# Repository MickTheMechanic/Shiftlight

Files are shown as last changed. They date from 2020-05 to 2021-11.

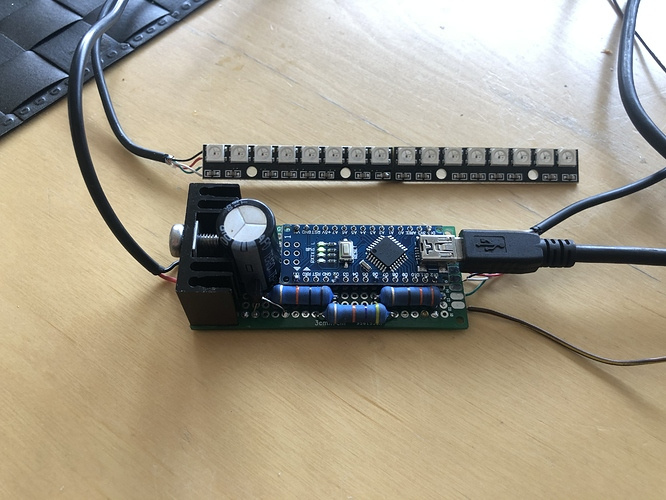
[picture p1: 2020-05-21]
Finished board.jpeg

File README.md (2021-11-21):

## Open-source Shiftlight

[vid](https://youtu.be/9aou7hNQFXM)

# An opensource shiftlight project using Arduino and Neopixel products

In this repository you will find;
- The .ino file that you can upload directly to your Arduino 
- A .png image of the wiring diagram
- A .jpeg image of how the finished assembly should look
- An .stl file for a housing for the shift light (Suits Daihatsu, but can be modified)
- An .stl file for a housing for the Arduino
- An .md file containing a detailed parts list.

# Currently the easiest DIY shiftlight on the world wide web, you're welcome ;)

b73128e0c34c0271b41c925a6889e2ce635afe49

02e61ff9bd5349ea1deae73b9c1757d51cc9f0a8

## Please note, there is a mistake in this schematic. A corrected schematic is shown in issue #4

72bc0fe16fb227eac94da071f4eaca564dbe03f3

77c8a71d32cf7a6d5637833e3bfcc7f0d2fdef7a

Notes:

- This example uses a voltage divider and transistor to pull down the the tacho signal from 12v,

if your car uses a 5v tacho signal this is not needed.

- You will need to download and install the adafruit neopixel library for IDE

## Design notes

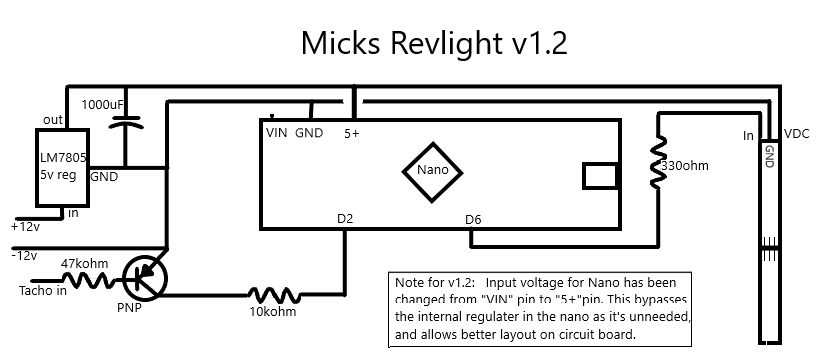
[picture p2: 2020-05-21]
revlight.png

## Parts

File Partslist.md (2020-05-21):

- Arduino nano
- 70mm x 30mm double sided Prototype PCB
- 1x 330 ohm resistor
- 1x 47 kohm resistor
- 1x 10 kohm resistor
- 1x 5v reg #7805
- 1x heatsink #V4330N (fits perfectly to the board and voltage reg)
- 1x PNP transistor #2N3906
- 1x 1000uF (min 6v) capacitor
- 2x neopixel 8LED strips #WS2812

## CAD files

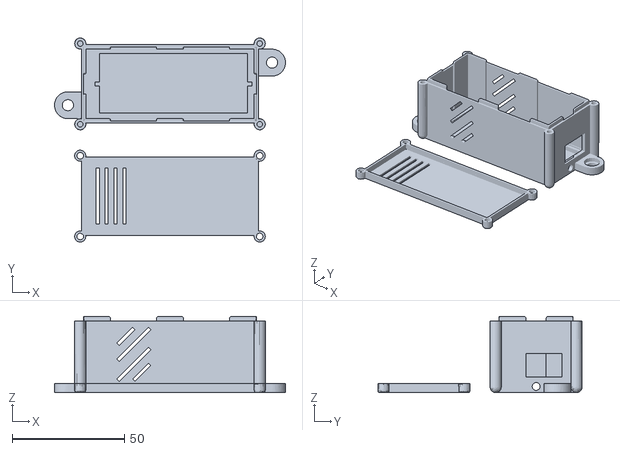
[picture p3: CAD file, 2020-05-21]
Shiftlight ECU case.stl
103.0 x 91.0 x 34.0

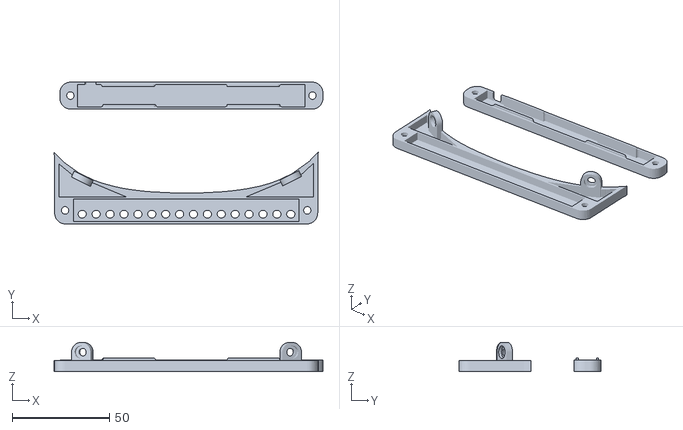
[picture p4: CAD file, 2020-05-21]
Shiftlight case Sirion M100.stl
138.5 x 73.0 x 15.0

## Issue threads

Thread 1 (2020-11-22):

Program only runs on USB power?

drftrds87, 2020-11-22:
I'm trying to use an external power source to power the Arduino nano but the program will not run with an external 12v to VIN. Any help would be appreciated.

michaelwilkinson1992, 2020-11-23:
You cannot run the Arduino Nano on 12v, it is a 5V Board. You need to build the circuit shown in the schematic, there is a voltage regulator included (LM7805).

You may need to purchase a new board, I would imagine the 12v directly to VIN has done some permanent damage.

michaelwilkinson1992, 2020-11-23:
Also note: the LM7805 has NO polarity protection, if you accidentally switch the wires during installation, the regulator will be permanently damaged

Closed 2020-11-23.

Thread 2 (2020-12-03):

Tach Input

adamgav5000, 2020-12-03:
Hi Michael,

I'm really looking forward to building and running this project. I have a few questions about the incoming tach signal...

Do you know where your vehicle reads its tach signal from? Is it the negative side of the coil?
You say the resistors etc are based off of a 12v signal. Is this signal a clean 12v square wave?

I am trying to get this to work with a YX160 pitbike engine which does not have an original tachometer signal. I am planning on taking a reading from the negative of the primary side of the coil. I believe this is susceptible to voltage surges of negative  200V. I am yet to check out the signal with an oscilloscope, but have found other peoples readings that suggest it may be a sawtooth pulse rather than a nice square pulse.

Can you suggest a method to reduce and clean the voltage to a level that can be applied to the base of the transistor.
What is the target voltage and current that is needed to be sent to the base?

My coding ability is non existent as is my circuit design knowledge, so any help is much appreciated!

Kind Regards
Adam

michaelwilkinson1992, 2020-12-03:
Hi, this particular circuit is designed to use with a 12v sqare wave signal.

The signal is the tacho output from the ECU.

You could definatly use the coil negative as a signal, but you would need to update the code a little bit to match the frequency of the coil signal. This can be easily calculated, all you need to know is how often the coil fires for one engine rotation.

But... I guess your bike does not have electronic ignition, rather a magneto style ignition coil. In this case you will need to do some research on how to convert this to some kind of signal that is not greater than 5v ( It shouldnt matter if you have a sawtooth, square wave, or sinus wave signal, as the arduino will still register the top and bottom of the signal as high/low).

The important thing is the lows are 0v and the highs are somewhere in the ballpark of 3-5v.

I reccomend reading the signal first with an occilliscope, if your signal does not exceed 15v the existing circuit should work.
If you are getting high induction spikes then you will need to clean up the signal somehow.

adamgav5000, 2020-12-13:
Sorry for the slow reply. Thank you for the information!

Closed 2021-11-21.

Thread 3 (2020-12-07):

Trying to run on a 6 cylinder

cpatersontn, 2020-12-07:
Mick,
Thanks for posting this project. We're looking forward to getting this running on our race car. We have a 1991 BMW 325i running the 6 cylinder engine. We've built the board as you specified and uploaded a modified version of your code. We are pulling the tach signal from the ECU wire that feeds the factory in-dash tach. The factory tach is working fine so we know it's getting good signal. The engine is firing 3X per revolution so we are assuming the frequency (at a given rpm) is (RPM/60)*3. We are testing at lower RPMs (don't want to upset the neighbors with rev'ing it to redline :)) so we calculated the lower RPMs between 1500 and 3100 (75Hz-155Hz). It idles at 800 RPM.

Once we start the car, the start-up sequence works and they flash one by one and then go off. However, regardless of how high we rev it, nothing else lights up. It's like it does the start-up sequence then somewhere it gets hung-up on lighting the LEDs (0,0,0). Stumped.

Here's the modified code:

//Shift Light V1.5

#include <Adafruit_NeoPixel.h>

#define PIN            6  //LED Data Pin
#define NUMPIXELS      16  //number of leds connected
Adafruit_NeoPixel pixels = Adafruit_NeoPixel(NUMPIXELS, PIN, NEO_GRB + NEO_KHZ800);

//Calculate the frequency of the tacho signal you are using and adjust the following values accordingly
//example: for a standard tacho signal on a 4 cylinder engine the frequeny is equal to the RPM divided by 30
const unsigned int onFrequency = 20;  //startup sequence, value represents engine speed higher than cranking and lower than idle
const unsigned int minFrequency = 75; // minimum frequency to begin turning on LEDs
const unsigned int maxFrequency = 155; // maximum frequency in normal range, after this value shift flash will occur
const unsigned int shiftFrequency = 165; // frequency range from max to shift when shifting should happen, after this value overrev flash will occur

//Set the color for each LED in the neo pixel strip
//Colors are set using an RGB value ranging from (0,0,0) to (255,255,255)
const uint32_t tachColor[NUMPIXELS] = {
  Adafruit_NeoPixel::Color(0, 120, 0),//green
  Adafruit_NeoPixel::Color(0, 120, 0),
  Adafruit_NeoPixel::Color(0, 120, 0),
  Adafruit_NeoPixel::Color(15, 105, 0),
  Adafruit_NeoPixel::Color(30, 90, 0),
  Adafruit_NeoPixel::Color(45, 75, 0),
  Adafruit_NeoPixel::Color(60, 60, 0),//orange
  Adafruit_NeoPixel::Color(75, 45, 0),
  Adafruit_NeoPixel::Color(90, 30, 0),
  Adafruit_NeoPixel::Color(105, 15, 0),
  Adafruit_NeoPixel::Color(120, 0, 0),//red
  Adafruit_NeoPixel::Color(0, 0, 120),//blue
  Adafruit_NeoPixel::Color(0, 0, 120),
  Adafruit_NeoPixel::Color(0, 0, 120),
  Adafruit_NeoPixel::Color(0, 0, 120),
  Adafruit_NeoPixel::Color(0, 0, 120),
};

//Set the frequency when each LED should turn on
//First LED turns on at minFrequency
const unsigned int lightShiftFreq[NUMPIXELS] = {
  minFrequency,
  80,
  85,
  90,
  95,
  100,
  105,
  110,
  115,
  120,
  125,
  130,
  135,
  140,
  145,
  150,
};

bool hasStartupSequenceRun = false; // only run startup sequence one time
const byte tachPin = 2;
unsigned long igfreq;

void setup() {
  pixels.begin(); // This initializes the NeoPixel library.
}

void loop() {

  float ighigh, iglow;
  unsigned long igcal1, igcal2;

  //measure period of tach signal
  ighigh = pulseIn(tachPin, HIGH);
  iglow = pulseIn(tachPin, LOW);

  igcal1 = 1000 / ((ighigh / 1000) + (iglow / 1000));

  //do it again
  ighigh = pulseIn(tachPin, HIGH);
  iglow = pulseIn(tachPin, LOW);

  igcal2 = 1000 / ((ighigh / 1000) + (iglow / 1000));

  //to filter out some noise, we only consider our measurement valid if they are similar in value, we accept the average.
  if ((igcal1 - igcal2) < 8) {
    igfreq = (igcal1 + igcal2) / 2;
  }

  if (hasStartupSequenceRun == false) {
    if (igfreq > onFrequency) {
    //run start sequence
    //LEDs will light up, flash and light out upon starting the engine.
      for ( int i = 0; i < NUMPIXELS; ++i) {
        pixels.setPixelColor(i, tachColor[i]);
        pixels.show();
        delay(50);
      }
      for(int a=0; a<10; a++) {
        pixels.fill(pixels.Color(0, 0, 120));
    	pixels.show();
    	delay(20);
    	pixels.fill(pixels.Color(0, 0, 0));
    	pixels.show();
    	delay(20);
       }
       for ( int i = 0; i < NUMPIXELS; ++i) {
        pixels.setPixelColor(i, tachColor[i]);
        pixels.show();
        }
       for ( int i = NUMPIXELS-1; i >= 0; --i) {
        pixels.setPixelColor(i, pixels.Color(0, 0, 0));
        pixels.show();
        delay(50);
      }
      hasStartupSequenceRun = true;
      pixels.fill(pixels.Color(0, 0, 0));
      pixels.show();
    }
      if (igfreq < onFrequency) {
    //resets hasStartupSequenceRun to false if engine stops but Arduino remains powered,
    //startupsequence will rerun upon restarting the engine
	hasStartupSequenceRun = false;
    }
  }

  if (igfreq < maxFrequency) {

    // normal operating range
    for ( int i = 0; i < NUMPIXELS; ++i) {
      if (igfreq > lightShiftFreq[i]) {
        pixels.setPixelColor(i, tachColor[i]);
      }
      else {
        pixels.setPixelColor(i, pixels.Color(0, 0, 0));
      }
    }
    pixels.show();
  }
  else if (igfreq >= maxFrequency && igfreq < shiftFrequency) {
    //shift flash
    //default color=blue
    //to change shift flash color, edit RGB value in following line
    pixels.fill(pixels.Color(0, 0, 120));
    pixels.show();
    delay(20);
    pixels.fill(pixels.Color(0, 0, 0));
    pixels.show();
    delay(20);
  }

  else if (igfreq >= shiftFrequency) {
    //overrev flash
    //default color=red
    //to change overrev flash color, edit RGB value in following line
    pixels.fill(pixels.Color(120, 0, 0));
    pixels.show();
    delay(20);
    pixels.fill(pixels.Color(0, 0, 0));
    pixels.show();
    delay(20);
  }
}

MickTheMechanic, 2020-12-07:
If you have an ocsilloscope please check your Signal wire and confirm you have a 12v square wave (I am not familiar with BMW Tacho Signal, it’s possible it’s a 5v Signal).

Does your car have a single coil with a distributor? If so, please try using coil negative.

Report back with results.

cpatersontn, 2020-12-07:
We don't have an ocsilloscope. If it's a 5V signal, then what do we need to modify (hardware and software)?

Yes, single coil with distributor. We tried the coil negative and it was very noisy.... LEDs jumped all over the place.

MickTheMechanic, 2020-12-07:
If its a 5v signal then you can feed it directly into the arduino, bypassing the transistor. But if its not 5v and you do that, you'll fry your arduino.

Do you maybe have a video showing what it looks like when using coil negative?

MickTheMechanic, 2020-12-07:
You could even check with a multimeter, if its a 12v signal you should read about 6v on the signal wire with engine running. If its a 5v signal you should read about 2-3v

cpatersontn, 2020-12-08:
Tach signal from ECU is 7.9V (set to DC on multimeter).

Here's the shift light attached to the negative on the coil. It always goes through the start-up sequence then just flashes red as at idle if it's over-reving. Our shiftFrequency is set to 165Hz just for testing but that should equate to 3300rpm if our equation is correct for this 6-cylinder (RPM/60)*3)

Link to video: [https://www.facebook.com/chris.paterson.399/videos/10219498587075256/](url)

MickTheMechanic, 2020-12-08:
Link doesnt work.

Are you able to test on another car?
Perhaps there is a problem with the circuit.

Have you tried using the original code, unchanged?

MickTheMechanic, 2020-12-08:
Can you upload photos of your circuit?
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
MickTheMechanic, 2020-12-19:
Its reading about 40kHz, but the signal should only be 100-200 Hz. There is some kind of interferance there somewhere.

-Double check your circuit, there is possibly something amiss there thats allowing interferance to be read as pulses.

-Check the routing of the signal wire, it should not be run along side any kind of signal wires for valves that are powered by PWM (things like idle control valve, AGR and so on)

-If you have the posibilitiy, perform a test without the alternator connected, its possible the alternator voltage is producing a ripple that is being picked up by the arduino.

It seems very strange that the arduino is reading such a high frequency, and not reading anything on the tacho signal. Perhaps the arduino has been damaged in some way, possibly by a voltage surge from the coil (induction voltage when the points/coil driver opens)

I have attached some extra photos so you can check your circuit.
It is also important that you are using the same kind of transistor (PNP, not NPN)

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

MickTheMechanic, 2020-12-19:
Please provide accurate information about your car, make model, build date, engine, ECU. I will take a look at work on monday and see if I can find a wiring diagram/somewhere where you can pick up a signal

cpatersontn, 2020-12-19:
Thanks Mick. Will check those this weekend.

Car is a 1991 BMW 325i, 6 cylinder. Stock ECU.

Here's my part list:
330k ohm 5W resistor
10k ohm 5W resistor
47k ohm 3W resistor
PNP Transistor ON Semi Bipolar Transistors
Heat sink
5 volt regulator
1000uF 20% 16V Vishay Aluminum Electrolytic Capacitor
Arduino Nano
Adafruit LEDs

MickTheMechanic, 2020-12-21:
If you have the 20 pin style BMW diagnostic port, try Pin 1 (listed as Drehzahl in below picture)

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

MickTheMechanic, 2020-12-21:
Does your car have one ignition coil, or 6.
please provide a picture of how you have connected to the ignition coil.

cpatersontn, 2020-12-22:
Our car has one standard cylindrical coil. Here is the attachment point to the negative side. I ran it directly to the Arduino without any other wires around it.
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

MickTheMechanic, 2021-02-24:
Did you get it working?

cpatersontn, 2021-03-01:
Unfortunately, no. The issue was either I got zero signal from the factory tach wire from the ECU or the signal from the coil was too noisy and just bounced around the signal. Thanks for your help and understanding the code and circuit. May just need to build another one from scratch to see if it was a hardware issue.

Sent from my iPhone

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

MickTheMechanic, 2021-04-06:
Hi,

I was working on a project recently which reminded me of your problem.

The project used some transistors, and I came to learn the hard way that not all transistors have the same pinout. E,C, and B pins vary from manufacturer to manufacturer. I even had two 2N2222A transistors with different pin layout, the only difference was a prefix printed on the housing.

I thought maybe this could be the problem. If you are still interested in getting this project up and running it might be a good place to start with the troubleshooting. You would need to download the datasheet for the particular transistor you have (should be available from the seller website) and confirm the pin layout matches how you have it connected.

cpatersontn, 2021-04-06:
Interesting..... will need to check

Would a higher resistor value cause issues with this circuit?

Sent from my iPhone

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

MickTheMechanic, 2021-04-06:
Yes it could have an influence. Transistors are not actually switched by the amount of voltage, but rather by the amount of current that runs through the base. This current is limited by the resistor connected to the base, so a different value resistor could have a negative effect.

also Different transistors have Different characteristics regarding switching speed, switching current, and so on.

I would first of all check the datasheet and make sure you have the pins connected correctly (in my last project I was pulling my hair out trying to find the problem, turns out the transistor I used that had „similar properties“ also had a different pin layout!).
If that doesn’t work I would swap it out with one that has the same part number as listed in the parts list, as the resistors have been sized
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

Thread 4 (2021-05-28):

Trying to get the project running

Lakshitha747, 2021-05-28:
Mike,

Thanks for the project. Trying to get the code working for my honda (4 cylinder). Did everything according to your diagram without using the LM7805 as im powering my Arduino Uno from my laptop for now. This works but I'm getting frequency values when my ECU wire is not connected and the the idle frequency is showing in the high 40000. The -12v, is it fixed to the chasis as earth or?. If you could find the time to help me that would be really great. Im sort of new to this and I have no idea whats going on

Thank you

MickTheMechanic, 2021-05-28:
Very strange indeed... the same problem was reported in #3

I will need to look into this further. I know of several other people who have successfully built the project without issues, so I am fairly confident it’s not an issue with the code.

Can you provide more information, like what you are using as a signal, does the bug also appear when you have the signal wire connected etc etc...

Lakshitha747, 2021-05-28:
Thanks for your help,

Yeah its the same when its connected. It cant be an issue with the code cause the first time I tested it I got the proper values. The idle frequency was at 30Hz and when pin was removed it was showing 0Hz

Lakshitha747, 2021-05-28:
Working on getting you the pictures. Actually didn't expect a reply so quickly

MickTheMechanic, 2021-05-28:
I found the problem, my wiring diagram is wrong... I will post an updated version in a few moments

Lakshitha747, 2021-05-28:
Thank you for the help.

MickTheMechanic, 2021-05-28:
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

please try this configuration with the PNP transistor and let me know how it works.

Also make sure your Arduino gnd pin has a connection to the car body when you are powering via the laptop.

Lakshitha747, 2021-05-28:
Alright thanks. I'll let you know how this goes

MickTheMechanic, 2021-05-30:
Did it work out for you?

Lakshitha747, 2021-05-30:
Sorry waiting on the transistors. Country is on lock down bit hard to get the stuff. I'll update the forum as soon as I get the parts and build the circuit. Is there another alternative to the transistor that you know of other than the PNP transistor #2N3906?

MickTheMechanic, 2021-05-30:
Do you have any other PNP transistors?

Lakshitha747, 2021-05-30:
s8550, s8050 transistor

MickTheMechanic, 2021-05-30:
You can try the S8550, it would probably work.

Lakshitha747, 2021-05-30:
Alright. I'll try with the S8550 and let you know

MickTheMechanic, 2021-06-03:
Any luck?

Lakshitha747, 2021-06-03:
Trying it right now with a S8050 transistor (cant seem to find my S8550 transistors). Trying to print igfreq but the serial monitor shows nothing. I have a random println in the loop and even that doesn't print. Can this be expected when running with this transistor?

Lakshitha747, 2021-06-03:
Ok so now its printing a bunch of zeros

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

Lakshitha747, 2021-06-03:
Yeah now I took the ground off and now its showing 50s 49s. When the revs increase it increases by like +1 not much and on idle and even when the vehicle is off its saying a constant 50. Looks like the transistor. I'll have get new ones

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

Lakshitha747, 2021-06-05:
Well my transistors finally came and I tried it with the 2N3906 and it works. Thanks for all your help with this. Just one more thing, when I do use this with the 12v, I can use a step down converter to reduce the voltage and power the Arduino and the rest of the circuitry will stay the same?

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

The frequencies are set pretty low

MickTheMechanic, 2021-06-05:
Yes, you can use either a stepdown or a linear regular, and the rest will stay the same.

Which wiring diagram worked for you in the end?

Lakshitha747, 2021-06-05:
This one

 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

Lakshitha747, 2021-06-05:
I'll close this issue now. Again thanks for your help with this.

JeFeRoJo, 2021-11-11:
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

Hello.

I just created an account here to ask you how you have implemented the display with the RPM counter.
I am also trying to get the project to work on my Honda (EUDM Civic EK3) and am going to test it again with the new published diagram.

Thanks!

Closed 2021-06-05.

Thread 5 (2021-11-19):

Trying to make it run (for a long time)

JeFeRoJo, 2021-11-19:
Hello!

First of all, thank you for sharing your project. I was looking to mount something similar in a simple way and this is great.
But not everything is happiness. I've been stuck with your project for almost a year. I can't get it to work.

A few days ago I took up the project again and saw that it updated the circuit (the position of the PNP transistor).

I have reassembled it following the new scheme. Same components.
The code has not been modified and I think that, could the problem be there?

My car is a Honda Civic EK 1996. D15Z6 engine from the European market.
I extract the signal from the cable that connects the original tacho/speedometer (blue wire in my case).
I'm just getting uncontrolled blinks. I attach a small video to show it:

https://www.youtube.com/watch?v=rK0u13ykE58

Could it be wrong values   in the code for the engine?
Any help would be appreciated. I would like to make it work after so long.

Thanks and regards

MickTheMechanic, 2021-11-20:
Hi,

My guess is your car uses some other kind of signal for the Tacho. Do you have access to an oscilloscope to check what kind of signal you have?

JeFeRoJo, 2021-11-20:
I don't have an oscilloscope because I've never used one but I can try to get a "cheap" one like this: shorturl.at/szQ16
It's enough?

However, in another thread here, a user has made it work on his Honda. It also added a screen.

For this reason, I was wondering if I have to edit values   of the code u is a circuit problem.

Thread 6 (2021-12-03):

finding schematics

eddygor, 2021-12-03:
Hi Mick. First off fantastic job, Thank you for posting this project. Your instructions are very clear even for a learner like myself. I am hoping to adapt this to work on my 1986 golf GTI. only issue I'm having is the note on the bottom of the schematic says  there is a mistake, and the correct schematic is in "issue 4". Where can I find issue 4 (or the correct schematic) as I am new to GitHub. many thanks eddy

hope I've posted this in the correct place

MickTheMechanic, 2021-12-04:
#4

Closed 2023-01-10.

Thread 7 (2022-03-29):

For building up the Shiftlight

sono0312, 2022-03-29:
Hello,
I am trying to build up your shiftlight for my car BMW E90 2005 which has an OBD2 port. I believe that it can give a signal RPM from PIN-9 on the OBD2 connector (according to my research).

I am still a beginner to do the sketch on the Arduino and need more time to learn/modify your sketch you posted already to match with what I want. I have checked your schematics and info of corrections on the wiring of PNP. I hope that 12-14V together with RPM can be wired from OBD2 as well.

I wonder if a register of 10k ohms on the Collector is a proper value for driving the Arduino D2 input? Is it working properly?

Thankyou for your help.

br//sono

sono0312, 2022-04-03:
I am trying to check the parameter around PNP transistor in the circuit below. I wonder if a register 10k ohms between Collector and G are a proper value. It might be too large. If Ic should be 20mA or so the register could be 250 ohms instead of 10k ohms.

https://github.com/MickTheMechanic/Shiftlight/issues/4#issuecomment-850627599

sono0312, 2022-04-03:
> I am trying to check the parameter around PNP transistor in the circuit below. I wonder if a register 10k ohms between Collector and G is a proper value. It might be too large. If Ic should be 20mA or so the register could be 250 ohms instead of 10k ohms.
>
> [#4 (comment)](https://github.com/MickTheMechanic/Shiftlight/issues/4#issuecomment-850627599)

I realized that 10k ohms on Corrector could be a pull-down register so it should not be a problem. Am I right?

MickTheMechanic, 2022-04-05:
It is a voltage divider to make an appropriate signal voltage

sono0312, 2022-04-05:
> It is a voltage divider to make an appropriate signal voltage

Hello,
Thankyou for the reply.
Now I was able to make a shift-light according to your information. Everything is working fine so far. To check the all the signal function I changed the frequency range to lower so that the test can be done at the lower RPM.
To check the Tach signal from OBD2, a serial monitor enabled so that I can seen the real time frequency value in response to the axel work.

Again, thankyou for your job done to make it happen!

regards

sono0312, 2022-04-16:
Found that a Line 121 starting with  "if (igfreq < onFrequency) {" and onwards need to be corrected.

===
      hasStartupSequenceRun = true;
      pixels.fill(pixels.Color(0, 0, 0));
      pixels.show();
    }
      if (igfreq < onFrequency) {
    //resets hasStartupSequenceRun to false if engine stops but Arduino remains powered,
    //startupsequence will rerun upon restarting the engine
	hasStartupSequenceRun = false;
    }
  }
===

it should be out side of startup sequence like below.

===
    }
  }
  if (igfreq < onFrequency) {
  //resets hasStartupSequenceRun to false if engine stops but Arduino remains powered,
  //startupsequence will rerun upon restarting the engine
    hasStartupSequenceRun = false;
===

otherwise "hasStartupSequenceRun" will never become false even the engine stops but Arduino remains powered.

sono0312, 2022-04-16:
Found that a Line 121 starting with "if (igfreq < onFrequency) {" and onwards need to be corrected.

  **hasStartupSequenceRun = true;
  pixels.fill(pixels.Color(0, 0, 0));
  pixels.show();
}
  if (igfreq < onFrequency) {
//resets hasStartupSequenceRun to false if engine stops but Arduino remains powered,
//startupsequence will rerun upon restarting the engine
hasStartupSequenceRun = false;
}
}**

it should be out side of startup sequence like below.

**}
}
if (igfreq < onFrequency) {
//resets hasStartupSequenceRun to false if engine stops but Arduino remains powered,
//startupsequence will rerun upon restarting the engine
hasStartupSequenceRun = false;**

otherwise "hasStartupSequenceRun" will never become false even the engine stops but Arduino remains powered.

MickTheMechanic, 2022-04-16:
thanks, ill update it when I have a chance to test it out

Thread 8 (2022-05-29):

tachometer wire

GH-WRX, 2022-05-29:
How are you sure it’s pin 9 on the obd2 connector?? every pin out i try and look at all says thier manufacturers, but i can’t find any information on what they are??

MickTheMechanic, 2022-05-29:
Pin 9 on the obd is reserved for manufacturer specific use, which on Daihatsu happens to be the RPM signal.

Baileyyyyy, 2022-05-29:
Are you able to help me find where the tacho is on a ford focus 2014 mk3? I cant find any information and the ford forums arnt any help; I know toyota also used 9 as rpm too

MickTheMechanic, 2022-05-30:
You need to do some research, what kind of ignition system you have and where you can tap into an rpm signal

baileyfpv, 2022-06-02:
Hey, found some diagrams, what do you think about the violet wire?
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

baileyfpv, 2022-06-02:
http://excesstext.com/tag/duratec/

there us this website too which has a full diagram of everything in the duratech engine but I cant seem to find the tacho? but that violet wire in the diagram above seems like it could work no? using the coils as the tacho signal for the less?

MickTheMechanic, 2022-06-02:
No, the violet wire isn’t the Tacho signal. It’s possible the Tacho signal is transmitted on the can-bus.

Do your coils have two wires or three?

baileyfpv, 2022-06-02:
Unsure, Id say 2 since its a 2.0l ti-dcv

baileyfpv, 2022-06-02:
Wait Its two since thats the diagram from my engine?

MickTheMechanic, 2022-06-02:
Yeah, can’t help you if you’re unsure. I suggest you take a look, and find a full wiring diagram for the engine electrics that matches your car and post it here

baileyfpv, 2022-06-02:
Surly you can take a quick look, I assure you its pretty hard, I don't see why its so secretive about wiring

MickTheMechanic, 2022-06-02:
What’s your engine code?

MickTheMechanic, 2022-06-02:
And how much power does the engine make? I need those things so I can find the correct wiring diagram

baileyfpv, 2022-06-02:
Scratch that its TXDB 120kw

MickTheMechanic, 2022-06-02:
Is it possible it’s the XTDB? 1.6l?? I can’t find the TXDB

baileyfpv, 2022-06-02:
2.0L not exactly sure if it is but google says it’s should be the TXDB from
2014

On Thu, 2 Jun 2022 at 10:29 PM, MickTheMechanic ***@***.***>
wrote:

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

MickTheMechanic, 2022-06-02:
What do the registration papers say? It’s important we have the right wiring diagram..

baileyfpv, 2022-06-02:
I’ll take a look tomorrow and let you know

On Thu, 2 Jun 2022 at 10:33 PM, MickTheMechanic ***@***.***>
wrote:

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

Baileyyyyy, 2022-10-11:
There is no information that I can find unless I’m looking wrong..

On Mon, 30 May 2022 at 7:50 PM, MickTheMechanic ***@***.***>
wrote:

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

Closed 2023-06-03.

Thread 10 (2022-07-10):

NodeMCU / ESP8266 weird flashing

craigrobbo, 2022-07-10:
Hi there.

I am still pretty new to coding and trying to learn, i tried the code on my NODEMCU, the initial start up animation seems to work fine (I have not  yet connected to my engine as I am awaiting my transistors) but every 5 seconds or so all the LEDs flash red for a very brief moment, on my Arduino UNO it doesn't do this.

I was hoping to migrate to the ESP platform as I have some custom PCB boards for an ESP8266 project which would suit this and keep the physical size package really small.

EDIT: Changing the colour of the "over rev protection" appears to change the colour of this flashing, so it seems to be attempting to display the over rev but only a single flash every 5 seconds, I did try changing the pins around in case this was an issue to no avail.

Thank you

Craig

Marius1418, 2022-09-02:
hello,

I have the same issue with Pico board, did you manage to solve it?

MickTheMechanic, 2023-01-10:
Is anything connected to the tacho signal input when this occurs? If not then its probably just noise being registered as frequency. Try gounding the tacho pine when bench testing.

Closed 2023-12-02.

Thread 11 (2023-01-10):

Please help me change the code.

A-Alikin, 2023-01-10:
Hello
To begin with, I want to express my gratitude for your work, and that you find time to help other people with their questions.
I used your design for my lexus is200. I also used 16 LEDs. However, there are some minor changes.
I changed the order of the LEDs (as in the diagram). everything works great and I love it. But each time the ignition is turned on, the initial startup animation will go on and the LEDs will light up in the order 1-2-3..16.
But in my case, this is slightly illogical and I wanted the starting animation to be in the following order: 1, 16 - 2, 15 - 3, 14 - 4, 13 - 5, 12 - 6, 11 - 7, 10 - 8, 9.

Could you help me to make changes to the code to get this order of the start animation?
Sincerely, Alexander.

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

MickTheMechanic, 2023-01-10:
Hey M8, nice work!

This was one of my first Arduino projects, Im glad you appreciate it and have added your own touch!

Here is how we change the code:

This part of the code contains the startup sequence:

```

 if (hasStartupSequenceRun == false) {
    if (igfreq > onFrequency) {
    //run start sequence
    //LEDs will light up, flash and light out upon starting the engine.
      for ( int i = 0; i < NUMPIXELS; ++i) {
        pixels.setPixelColor(i, tachColor[i]);
        pixels.show();
        delay(50);
      }
      for(int a=0; a<10; a++) {
        pixels.fill(pixels.Color(0, 0, 120));
    	pixels.show();
    	delay(20);
    	pixels.fill(pixels.Color(0, 0, 0));
    	pixels.show();
    	delay(20);
       }
       for ( int i = 0; i < NUMPIXELS; ++i) {
        pixels.setPixelColor(i, tachColor[i]);
        pixels.show();
        }
       for ( int i = NUMPIXELS-1; i >= 0; --i) {
        pixels.setPixelColor(i, pixels.Color(0, 0, 0));
        pixels.show();
        delay(50);
      }
      hasStartupSequenceRun = true;
      pixels.fill(pixels.Color(0, 0, 0));
      pixels.show();
    }
      if (igfreq < onFrequency) {
    //resets hasStartupSequenceRun to false if engine stops but Arduino remains powered,
    //startupsequence will rerun upon restarting the engine
	hasStartupSequenceRun = false;
    }
  }

```

These are the two interesting parts:

```

 for ( int i = 0; i < NUMPIXELS; ++i) {
        pixels.setPixelColor(i, tachColor[i]);
        pixels.show();
        delay(50);
      }
//................................................................................//
       for ( int i = NUMPIXELS-1; i >= 0; --i) {
        pixels.setPixelColor(i, pixels.Color(0, 0, 0));
        pixels.show();
        delay(50);
      }

```

These loops will squentially turn on or off one pixel followed by a delay.

i represents the loop iteration, and NUMPIXELS represents the iteration at which the loop should stop.

To achieve the desired effect we should be able to halve the loop iterations, and count up and down simultainously to meet in the middle.

```

for ( int i = 0; i < NUMPIXELS/2; ++i) {
        pixels.setPixelColor(i, tachColor[i]); //turn on pixel counting up from 0
        pixels.show();
        int j = NUMPIXELS-1; //pixel address begins at 0, so we subtract 1 from NUMPIXELS to have the address of the last one
        j = NUMPIXELS - i; //count down from the last address each loop iteration
        pixels.setPixelColor(j, tachColor[j]); //turn on pixel counting down from NUMPIXELS
        pixels.show();
        delay(50);
      }
//................................................................................//
      for ( int i = 0; i < NUMPIXELS/2; ++i) {
        int j = (NUMPIXELS/2)-1; //set j to one less than 1/2 NUMPIXELS
        j = j - i; //Count down from half way
        pixels.setPixelColor(j, pixels.Color(0, 0, 0));
        pixels.show();
         j = NUMPIXELS/2; //set j to 1/2 NUMPIXELS
        j = j - i; //Count upfrom half way
        pixels.setPixelColor(j, pixels.Color(0, 0, 0));
        pixels.show();
        delay(50);
      }

```

Test it out and let me know :)

A-Alikin, 2023-01-11:
Thank you fast reply.
I'll test it today and give you feedback. good day.

A-Alikin, 2023-01-11:
It works !!  I am very happy!  thank you!!  Best regards from Russia, Alexander.

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

MickTheMechanic, 2023-01-11:
Nice

Closed 2023-01-11.

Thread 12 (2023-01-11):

Help for running on single cylinder engines

TechFreak9356, 2023-01-11:
Hi there, I came across your project of a DIY shift light and I figured it would be cool to be able to install one like this to my single cylinder motorcycle. I would like to learn more and better understand how the code works, especially in detecting the engine RPM through frequency from tach in or crank position sensor or magneto pickup, etc.

I am trying to adapt your project to my single cylinder but I can't quite figure it out, or to be exact....not sure of how the frequency is calculated and/or measured, since the project is originally for 4 cylinder cars. I'm not that familiar with engines, and googling only made me more confused as well so I was not quite sure with my understanding of the frequency measurement.

Any help would be appreciated, thank you

MickTheMechanic, 2023-01-11:
Hi.

You need to ask yourself what will you use as a signal. How many times do you have this signal per cank rotation.

Number of signals per crank rotation * RPM / 60

So if you have a single cylinder 4 stroke then you will use the ignition coil driver as a signal, then you have one signal for every two rotations, so mathematically speaking 0.5 signals per crank rotation.

(A 2 stroke signle cylinder would have 1 signal per rotation)

Multiply by the RPM you want the shift light to be triggered at:

0.5 signals per rotation * 5000 RPM

= 2500 signals per crank rotation

Then divide by 60 to convert from signals per minute to signals per second, AKA Hertz, AKA frequency

2500/60

= 41.6 Hz

Thats how it works :)

TechFreak9356, 2023-01-11:
Thank you very much for helping out. I have edited my original post to include some more details regarding my motorcycle and my setup.

Somehow my digital dash which, as the seller said, interprets 16.6Hz @ 1000RPM for the RPM mode compatible with my motorcycle. This calibration is accurate with the stock CDI unit (which I accidentally got killed). The afternarket CDIs on the other hand, is not detected at all by the digital dash. Like I said, only the analog tachometer can then detect it, which further complicates the computation for RPM (but I understood how it's now computed - 8.33Hz @ 1000RPM).

Was it possible that my aftermarket CDI was producing way higher voltage/power than the stock and is causing the digital tach not to recognize it? or is it releasing a signal that's out of range?

The analog tachometer cant detect the RPM signal from the RPM pin of the aftermarket CDI unit, but the digital dash can, only thing is, it's inaccurate once it gets past 4000RPM (My engine pushes 13000RPM as I verified on the analog tach connected to ignition coil positive). The opposite happens when I connect the digital dash to the ignition coil out (it has no reading at all) and the analog tach on the RPM pin of CDI (no reading).

I haven't tried to actually build the arduino yet and test it for myself. But, in case I might need to plug directly on the ignition coil positive, and the aftermarket CDI is actually pushing higher voltage through the line, will the resistors be enough to handle that higher voltage? I still have no idea what frequency the CDI RPM pin pushing out since the dash's 16.6Hz is twice that of our computed 8.33Hz @ 1000 RPM

MickTheMechanic, 2023-12-02:
You will probably need to include a diode to stop induction voltages damaging the Arduino if you connect directly to the coil.

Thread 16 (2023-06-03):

tacho wire for 2008 wrx ?

GH-WRX, 2023-06-03:
Hey, Any change on some help on finding the wire to splice for the GH-Wrx 2008?

GH-WRX, 2023-06-03:
i’m hoping it’s B136 pin 22 ???
[ecu pinout](https://www.justanswer.com/subaru/3j3e4-subaru-ecu-diagram-wrx-just-location-rpm-signal.html)

MickTheMechanic, 2023-12-02:
That looks like the right one. Please check with oscilloscope or workshop manual to see if it’s a 5v or 12v wave

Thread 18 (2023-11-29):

2009 Mustang GT help (V8)

LunixXd, 2023-11-29:
Hey Mike I stumbled across your post when looking to make things in my avionics class. I’m currently a student and have access to many things such as an oscilloscope so I thought I would attempt to make this shift light work in my car.

I’ve done some research trying to figure out how to connect this and I have remade your schematic v1.2 on a pcb board with the dip trace software  and im going to print it tomorrow at school. I was wondering how to safely connect this without blowing anything up in my vehicle, I care about it. With that being said Ive seen many people pull the tacho in from the coil driver wires as seen in this post from an official tach light company, raptor performance. ( https://www.raptorperformance.com/pages/raptor-shift-light-install-mustang-2005-2010-4-6l-5-4l-v8 ) is that where I should pull a tach signal for your circuit or should I go through via obd2, I’m not sure what Pinout provides rpm with my obd either as all companies seem to be different. I can provide photos of the circuit in a few days after I build it and give you any other vital info you need to help out. Any input is appreciated and thank you for sharing this information with us.

Ps: this is the first time I’ve ever really done anything this advanced with electrics and Arduinos so I’m learning as I go.

MickTheMechanic, 2023-11-30:
Hi,

so for a signal you just need something that is rpm relevant, you could use the signal for the ignition coil, the cam sensor, the Tacho signal from behind the dash, and so on. You just need to have a think about home many times per rotation the signal you are using triggers, and calculate the shift frequencies in the code accordingly.

The signal input on the board goes through a voltage divider to lower the voltage down to an acceptable level for the Arduino. If you are using a 5v signal then you don’t need these.

The Tacho signal on the OBD connector seems to be only Daihatsu and a few other Japanese manufacturers, consult a workshop manual/wiring diagram to see if this is also present on your car. I can’t say if American manufacturers also did this.

Please be aware that there was a mistake in the wiring diagram that is shown in README.me. There is a link there to an issue where a sketch is shown showing the correct connection of the transistor. Please take a look at that if you haven’t already.

M52byfix, 2023-12-02:
Hi friend. I'm setting up the circuit right now. But your transistor connection seems to be wrong. And my car has 6 coils. Do I need a transistor? And is there a problem with the circuit diagram? I've tried many times. There is a problem. The transistor connection is questionable. I would be very glad if you could help. I am waiting for your reply.

MickTheMechanic, 2023-12-02:
As I said earlier, the correct transistor connection is shown in issue #4

MickTheMechanic, 2023-12-02:
![Uploading IMG_8759.jpeg…]()

M52byfix, 2023-12-02:
My rpm signal is 5v. Should I still use transistors? And without a transistor, is there a difference in the circuit diagram?

MickTheMechanic, 2023-12-02:
You should be able to connect the 5v signal directly to the gpio pin without any need for a voltage divider or transistor.

MickTheMechanic, 2023-12-02:
Keep In mind that the Arduino needs to have a ground connection to the car

M52byfix, 2023-12-02:
Gpio. I didn't understand that. Maybe d2 pin?

MickTheMechanic, 2023-12-02:
Yes, gpio is just another name for the Arduino pin

MickTheMechanic, 2023-12-02:
Just connect your 5v signal directly to the d2 pin

M52byfix, 2023-12-02:
D2. Is this true. Because I threw away 2 arduino nanos. Yes, this is a shame. I tried all kinds of remedies to make it work. And the arduino nano is broken. X 🙈

M52byfix, 2023-12-02:
D2 I'm going to put a 10k resistor between the rpm signal cable and the rpm signal cable. As a precautionary measure

MickTheMechanic, 2023-12-02:
That should be ok

M52byfix, 2023-12-02:
I am grateful for your quick replies. Thank you very much

M52byfix, 2023-12-03:
> Bu iyi olmalı

Hi friend. It worked, and it worked. But sometimes it works inconsistently. I saw a video of a Honda. It has a Honda-like problem and sometimes it doesn't work at all for a while.

LunixXd, 2023-12-06:
Finally got the board complete after waiting for shipping, I will be testing it in the lab come morning, I’ll let you know how well it functions once I get it installed. but in the meantime here are photos of the board

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

Brown is ground, red Is power and green is signal, just for the time being. The board printed too small during the build so I readjusted it to make it work. I can’t drill holes in a straight line for the life of me so I just cut the legs of the arduino and lined them where I needed them then soldered connections.

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

This last photo is the board in our schematic  software, diptrace. Showing it just in case I did anything incorrectly.

LunixXd, 2023-12-06:
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

It works! Now when connecting it to my cool should I use the positive side for the tach in signal? When I flip the leads of the signal generator for a negative wire it doesn’t pick up anything.

LunixXd, 2023-12-07:
I had posted a photo of the schematic above, it follows the same connection as the paper drawing that mick drew

M52byfix, 2023-12-08:
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
I did without a transistor. But it is more advantageous to use transistors.

LunixXd, 2023-12-09:
Mick, I had it installed and here’s what happen: I turn the car on and the startup animation runs as normal, after that the lights blink red at an idle then I reved it and they turned off permanently. I uninstalled it and was going to do some troubleshooting of my own however, my question if my car is having an output from the coil as pulses per minute. Would I need to convert the pulses to a 12v signal, if so how? Or should they be fine like that after altering the code?

MickTheMechanic, 2023-12-09:
Add a Serial.print to the code to print the frequency to the serial monitor

M52byfix, 2023-12-09:
> Frekansı seri monitöre yazdırmak için koda bir Serial.print ekleyin
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
What is the purpose of 10k resistance. And why does it go to the gnd line. Is it necessary to put a resistor between the transistor and the D2 pin?

MickTheMechanic, 2023-12-11:
You have a 5v signal correct? If that’s the case then you don’t need any transistor or resistor. Try connecting directly to D2

the 10k and 47k resistors create a voltage divider, which drops the voltage.

MickTheMechanic, 2023-12-11:
Also make sure the Arduino is connected to the vehicle ground

LunixXd, 2023-12-11:
Hey mick, do you think this would be possible to make? It looks too simple to not attempt to especially with its high price all it does is Converts Low-Voltage/High-Current Pulse To A Clean 12-Volt Square Wave.

MickTheMechanic, 2023-12-11:
If you have a 5v signal then connect directly to D2.

What you are asking is pointless, you want to convert a 5v signal to 12v so that you can convert it back to 12v.

Just try to connect directly to D2 if you are sure you have a 5v signal

LunixXd, 2023-12-11:
Ah I see, that makes more sense. I need to use my brain more often lol. But what doesn’t make sense is the hyperactive hz signal I’m receiving from the coil. It doesn’t even seem correlated to the rpm’s when I reved it and I can’t get a good stable reading. The circuit works just fine on the bench and that’s why I was looking at this adapter for the engine but maybe your fix may work I will have to test it down the road as school is currently closed for break. They use that adapter on my car for mechanical and electrical shift lights. There isn’t a problem with your circuit but there is one with  my vehicle and how it gets its rpm signal, thank you for taking the time to respond to me.

MickTheMechanic, 2023-12-11:
If you are using this circuit with a 5v signal then it would explain your sporadic frequencies, since you are not getting a proper high (5v) low (0v) logic. You are getting something like 0v to 2v because the voltage is being divided. So sometimes a high is being detected as a high and sometimes a high is being detected as a low.

this is why I keep insisting you test with the 5v signal directly to D2.
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
M52byfix, 2023-12-26:
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

You need a frequency generator. Square wave frequency generator

MarcPerformance, 2023-12-26:
M52byfix , thanks for the quick response. I built this device from the youtube clip. Can I do these tests with it?

https://www.youtube.com/watch?v=GBmlMa-vJ8c&list=PLsp5MpqlTBRZajQEVdIYyT1N4g78S8RrR&index=36

Marco

M52byfix, 2023-12-26:
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
https://youtu.be/Dq0noaVAR50?si=JwWL_Y8V5ibtb3HS

This is my video. Watch

MarcPerformance, 2023-12-26:
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

I managed to test it on the work table!  🤩

LunixXd, 2024-01-18:
Mick, late response but the voltage was too high for the chip and I blew it to be honest, got a new one installed, works on the test bench just fine, tried it the in the car again, same results. I’m not sure where else I could pull a hz signal related to the tach via obd or the back of the gauge cluster. Is there any other way of doing this? I have no clue how my car gets its RPM signal at this point maybe the ecu under the hood??? But still at square one again what would you suggest I do?
Thx for any input

LunixXd, 2024-01-26:
It seems the coil I chose which is closest the driver is a bit fuzzy when at a flatline on the o-scope. (I don't think coil is faulty but could be a possibility.) Would a Schmitt trigger work well in combination with the board to get a clean precise output on the lights? Also, would overhauling or modifying any part of code allow compatibility between a coil connection? Simply put, my car doesn't output the right signal for the board so I have to do something before the board to clean/compute the signal.

LunixXd, 2024-01-27:
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
you said im supposed to be getting square waves too correct? These are the type of waves I get from the coil connecting with the o-scope.

LunixXd, 2024-03-26:
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
Was able to get it working and installed quite nicely, I had to go through the ecu to get a signal however ford blocks the pin (25) that you have to get to and I had to find a donor Mustang to get the right square connecting pin. To anyone else attempting this, save yourself time and go through the ecu.

Closed 2024-03-26.

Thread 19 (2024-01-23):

Compatibility with OBD2 Standard (2005 Suzuki Swift)

ElectronicallyE, 2024-01-23:
Hi @MickTheMechanic,

I'm trying to make your shift light project compatible with a 2005 Suzuki Swift EZ RS415 which support K-line communication known as [ISO 9141-2](https://www.suzuki-forums.com/threads/suzuki-swift-ecu-reading.277364/post-1622460) (ISO 14230-4 is backwards compatible).

Direct quote from the [Suzuki workshop service manual](https://www.allcarmanuals.com/factory-service-manual-233-Suzuki-Swift.html):
_**Data Link Connector (DLC)**
DLC (1) is in compliance with SAE J1962 in the shape of connector and pin assignment.
OBD serial data line (3) (K line of ISO 9141) is used for SUZUKI scan tool or OBD generic scan tool to communicate with ECM, Air bag SDM, immobilize control module (in ECM), BCM (Body electrical Control Module), TCM (Transmission Control Module) and ABS control module._

Looking at your [forum post](https://livetodai.com/t/arduino-rpm-light-shift-light/2545), you are using pin 9 for the RPM signal. I can't seem to find a OBD2 protocol that uses pin 9. Diagrams online state it is 'vendor option', 'manufacturer' or 'make/model specific'.

A few questions:
1. Could you please let me know the OBD2 standard used by your Daihatsu M100 (1998-2004) which the project is designed for?
2. Do you know if my car is compatible with your circuit diagram and code?

I have an oscilloscope to verify the signal type. If you would like me to verify, please let me know what I need to check.

Thanks,

Lachlan

yu835730500, 2024-03-09:
Arduino board (can use Nano, Teensy, Pro Micro, Uno....)
OBD II connector
CAN Bus MCP2515 module

ElectronicallyE, 2024-03-11:
Thanks mate, much appreciated.

Closed 2024-03-11.

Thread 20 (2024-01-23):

PCB Design Request

ElectronicallyE, 2024-01-23:
Hi @MickTheMechanic,

Reading your 'Live to Dai' forum post titled [Arduino RPM Light / Shift Light](https://livetodai.com/t/arduino-rpm-light-shift-light/2545), I see you have designed a [custom PCB](https://livetodai.com/t/arduino-rpm-light-shift-light/2545/6) for this project. Are you willing to share your design?

Thanks,

Lachlan

ElectronicallyE, 2024-01-23:
Found in your [Gear_Indicator](https://github.com/MickTheMechanic/Gear_Indicator/tree/main) project.

Closed 2024-01-23.

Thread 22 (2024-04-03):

Startup animation restart after engine stops

LunixXd, 2024-04-03:
I’d like to get the code to preform a restart when the engine is inactive, I’d imagine I’d measure the frequency at one of the current pins and have the Arduino run a reset code. I’m not well versed in coding so I was hoping you could help lead me in the right direction to get this to work. Alternatively I could find a wire in my car that’s 12 volts switched so that it manually restarts.

LunixXd, 2024-04-06:
Also, is there a way to switch between different code presets with a click of a button?

MickTheMechanic, 2025-08-24:
That is definitely doable, I’m pretty sure the code is already there. There is a threshold frequency value, if the input frequency drops below this value it raises a flag, which triggers the start sequence one the frequency comes above the threshold again.

MickTheMechanic, 2025-08-24:
Move lines 121 - 125 to line 127 (outside the if statement) and it should work

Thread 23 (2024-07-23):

X issue with speedo voltage.

JiNxXx0013, 2024-07-23:
Hey mick,
 First of all thanks for making this accessible for everyone. I’m having a issue with my incoming voltage from the rpm it’s s 9 Volts. I’m trying to see what I can do to step it down, I’ve tried a higher resistor but hasn’t changed the voltage. Any suggestions? The car is a 99 Honda civic.  Also I redid your schematic with a change on a pin location is this correct?
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

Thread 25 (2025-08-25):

Verification of circuit - Rev Light

Matheu-4AGE, 2025-08-25:
Hi there

Just a quick question for the wizard behind this Rev Light @MickTheMechanic, firstly this is a great idea and circuit!! I have been thinking of recreating it for my car for a while now and eventually I have started it.
I used the V1.2 schematics (temporarily using the 5v pin) to build the circuit and I created an Arduino code just to run the Neo pixel LED to see if the regulator will be able to keep up with the current draw. So obviously the led part of the circuit works 100%. I added a 1k pot to bring the brightness down a little to try and keep the regulator a little cooler.
But I just need to know if the transistor and cap is wired correctly because I will be trying to install this in my car after I scratch around and find a proper tach signal to use.

Any feedback would be highly appreciated!! Thanks

I have attached pics of my rough circuit, everything will look better once everything is tested and works properly.

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

MickTheMechanic, 2025-08-25:
Brightness of the neopixel LEDs is normally adjusted in the code.

The transistor schematic in readme.me is wrong, there is a hand drawn schematic in issue #4 with the correct one (look under closed issues), but from what I can see your one seems ok. Make sure you have the 47k and 10k resistors included in the transistor schematic, unless you are using a 5v Tacho Signal.

The capacitor is just to help smoothen voltage, not much can go wrong there. It’s probably not needed at all. I designed this a long time ago, when i didn’t really know what I was doing, that’s why all the component values are huge.

MickTheMechanic, 2025-09-01:
So the input voltage should be 0-3.3v on the Arduino, so that seems ok?

If you want a pot to adjust brightness, I’d recommend connecting the pot to the Arduino and Controlling the brightness that way. Dimming the LEDs by decreasing the input voltage might lead to unexpected behavior, since these are digital components.

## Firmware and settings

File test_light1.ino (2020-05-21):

//Shift Light V1.5

#include <Adafruit_NeoPixel.h>

#define PIN            6  //LED Data Pin
#define NUMPIXELS      16  //number of leds connected
Adafruit_NeoPixel pixels = Adafruit_NeoPixel(NUMPIXELS, PIN, NEO_GRB + NEO_KHZ800);


//Calculate the frequency of the tacho signal you are using and adjust the following values accordingly
//example: for a standard tacho signal on a 4 cylinder engine the frequeny is equal to the RPM divided by 30
const unsigned int onFrequency = 20;  //startup sequence, value represents engine speed higher than cranking and lower than idle
const unsigned int minFrequency = 123; // minimum frequency to begin turning on LEDs
const unsigned int maxFrequency = 235; // maximum frequency in normal range, after this value shift flash will occur
const unsigned int shiftFrequency = 250; // frequency range from max to shift when shifting should happen, after this value overrev flash will occur


//Set the color for each LED in the neo pixel strip
//Colors are set using an RGB value ranging from (0,0,0) to (255,255,255)
const uint32_t tachColor[NUMPIXELS] = {
  Adafruit_NeoPixel::Color(0, 120, 0),//green
  Adafruit_NeoPixel::Color(0, 120, 0),
  Adafruit_NeoPixel::Color(0, 120, 0),
  Adafruit_NeoPixel::Color(15, 105, 0),
  Adafruit_NeoPixel::Color(30, 90, 0),
  Adafruit_NeoPixel::Color(45, 75, 0),
  Adafruit_NeoPixel::Color(60, 60, 0),//orange
  Adafruit_NeoPixel::Color(75, 45, 0),
  Adafruit_NeoPixel::Color(90, 30, 0),
  Adafruit_NeoPixel::Color(105, 15, 0),
  Adafruit_NeoPixel::Color(120, 0, 0),//red
  Adafruit_NeoPixel::Color(0, 0, 120),//blue
  Adafruit_NeoPixel::Color(0, 0, 120),
  Adafruit_NeoPixel::Color(0, 0, 120),
  Adafruit_NeoPixel::Color(0, 0, 120),
  Adafruit_NeoPixel::Color(0, 0, 120),
};


//Set the frequency when each LED should turn on
//First LED turns on at minFrequency
const unsigned int lightShiftFreq[NUMPIXELS] = {
  minFrequency,
  130,
  137,
  144,
  151,
  158,
  165,
  172,
  179,
  186,
  193,
  200,
  207,
  214,
  221,
  228,
};

bool hasStartupSequenceRun = false; // only run startup sequence one time
const byte tachPin = 2;
unsigned long igfreq;

void setup() {
  pixels.begin(); // This initializes the NeoPixel library.
}

void loop() {

  float ighigh, iglow;
  unsigned long igcal1, igcal2;

  //measure period of tach signal
  ighigh = pulseIn(tachPin, HIGH);
  iglow = pulseIn(tachPin, LOW);

  igcal1 = 1000 / ((ighigh / 1000) + (iglow / 1000));

  //do it again
  ighigh = pulseIn(tachPin, HIGH);
  iglow = pulseIn(tachPin, LOW);

  igcal2 = 1000 / ((ighigh / 1000) + (iglow / 1000));

  //to filter out some noise, we only consider our measurement valid if they are similar in value, we accept the average.
  if ((igcal1 - igcal2) < 8) {
    igfreq = (igcal1 + igcal2) / 2;
  }

  if (hasStartupSequenceRun == false) {
    if (igfreq > onFrequency) {
    //run start sequence
    //LEDs will light up, flash and light out upon starting the engine.
      for ( int i = 0; i < NUMPIXELS; ++i) {
        pixels.setPixelColor(i, tachColor[i]);
        pixels.show();
        delay(50);
      }
      for(int a=0; a<10; a++) {
        pixels.fill(pixels.Color(0, 0, 120));
    	pixels.show();
    	delay(20);
    	pixels.fill(pixels.Color(0, 0, 0));
    	pixels.show();
    	delay(20);
       } 
       for ( int i = 0; i < NUMPIXELS; ++i) {
        pixels.setPixelColor(i, tachColor[i]);
        pixels.show();
        }
       for ( int i = NUMPIXELS-1; i >= 0; --i) {
        pixels.setPixelColor(i, pixels.Color(0, 0, 0));
        pixels.show();
        delay(50);
      }
      hasStartupSequenceRun = true;
      pixels.fill(pixels.Color(0, 0, 0));
      pixels.show();
    }
      if (igfreq < onFrequency) {
    //resets hasStartupSequenceRun to false if engine stops but Arduino remains powered, 
    //startupsequence will rerun upon restarting the engine
	hasStartupSequenceRun = false;
    }
  }
	
  if (igfreq < maxFrequency) {

    // normal operating range
    for ( int i = 0; i < NUMPIXELS; ++i) {
      if (igfreq > lightShiftFreq[i]) {
        pixels.setPixelColor(i, tachColor[i]);
      }
      else {
        pixels.setPixelColor(i, pixels.Color(0, 0, 0));
      }
    }
    pixels.show();
  }
  else if (igfreq >= maxFrequency && igfreq < shiftFrequency) {
    //shift flash
    //default color=blue
    //to change shift flash color, edit RGB value in following line
    pixels.fill(pixels.Color(0, 0, 120));
    pixels.show();
    delay(20);
    pixels.fill(pixels.Color(0, 0, 0));
    pixels.show();
    delay(20);
  }

  else if (igfreq >= shiftFrequency) {
    //overrev flash
    //default color=red
    //to change overrev flash color, edit RGB value in following line
    pixels.fill(pixels.Color(120, 0, 0));
    pixels.show();
    delay(20);
    pixels.fill(pixels.Color(0, 0, 0));
    pixels.show();
    delay(20);
  }
}
